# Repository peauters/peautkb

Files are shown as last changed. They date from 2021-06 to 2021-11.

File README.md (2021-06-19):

# Peautkb

## Intro
This is my first foray into custom built mechanical keyboards. I designed this as a mini project to get into pcb design and embedded code in `rust`. 

It has been awesome.

## Details
This board takes a lot of inspiration from the [Corne](https://github.com/foostan/crkbd) and [Kyria](https://blog.splitkb.com/blog/introducing-the-kyria) boards. 

I really liked the 3 rows from the Corne, as well as the rotaries from the Kyria. I wanted a single row thumb cluster and a column stager that fitted my hands. In then end, I ended up with what is in this repo.

## Firmware
Before I really had much info about open source keyboards, I decided I wanted to write my own firmware in `rust`. A well supported chip and board is the (WeAct MiniSTM32F4x1)[https://github.com/WeActTC/MiniSTM32F4x1] aka "the blackpill".

This board has a different footprint to a Pro Micro, which in hindsight has probably made this board very niche. I know of other blackpill boards (like the [Grandiceps](https://shop.tokas.co.uk/product/grandiceps-split-keyboard-kit/?v=79cba1185463)), but they seem limited at the moment.

The firmware is custom, written in `rust` using the [keyberon](https://github.com/TeXitoi/keyberon) as a base. At the moment, it manages communication between each side, the ssd1306 displays and has code to enable media keys in a second usb HID report. The most important feature is bongo cat animated displays. Thank you to [dancarrol](https://github.com/dancarroll/qmk-bongo) for the inspiration.

### How to build the firmware
- Install rust (see [here](https://www.rust-lang.org/tools/install))
- Install the compile target for the black-pills `rustup target install thumbv7em-none-eabihf`
- Install binutils to create a binary file `cargo install cargo-binutils` and `rustup component add llvm-tools-preview` 
- Build the binary `cargo objcopy --release -- -O binary out.bin`
- Put the black-pill in dfu boot loader. Hold the `NRST` and `BOOT0` buttons at the same time, then let go of `NRST` while still holding `BOOT0` button for a second longer.
- Check you can see it with `lsusb`
- Flash with dfu-util or similar
- Repeat for both sides

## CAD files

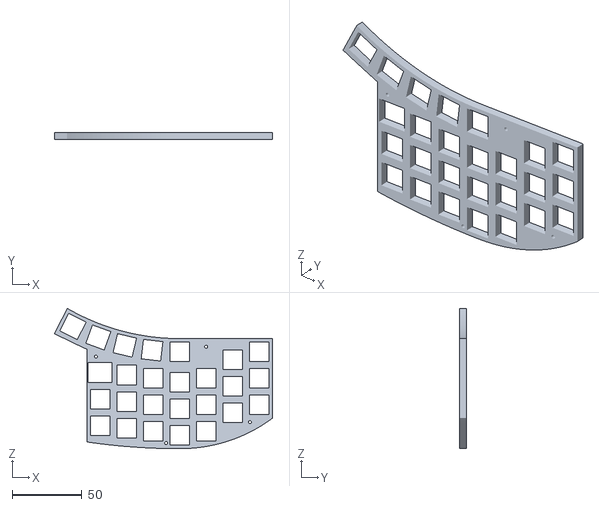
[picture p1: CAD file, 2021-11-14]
case/plate-right.stl
156.1 x 4.80 x 100.5

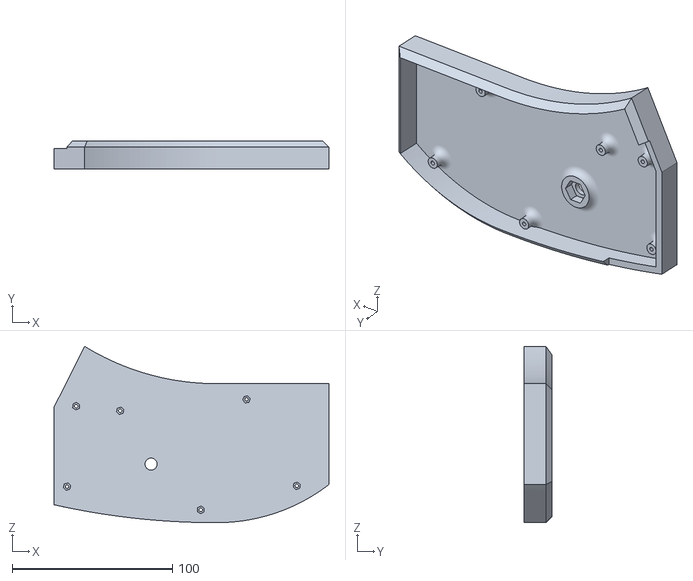
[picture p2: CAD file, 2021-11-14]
case/base-right.stl
171.8 x 17.5 x 110.1

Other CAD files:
case/base-left.stl
case/plate-left.stl

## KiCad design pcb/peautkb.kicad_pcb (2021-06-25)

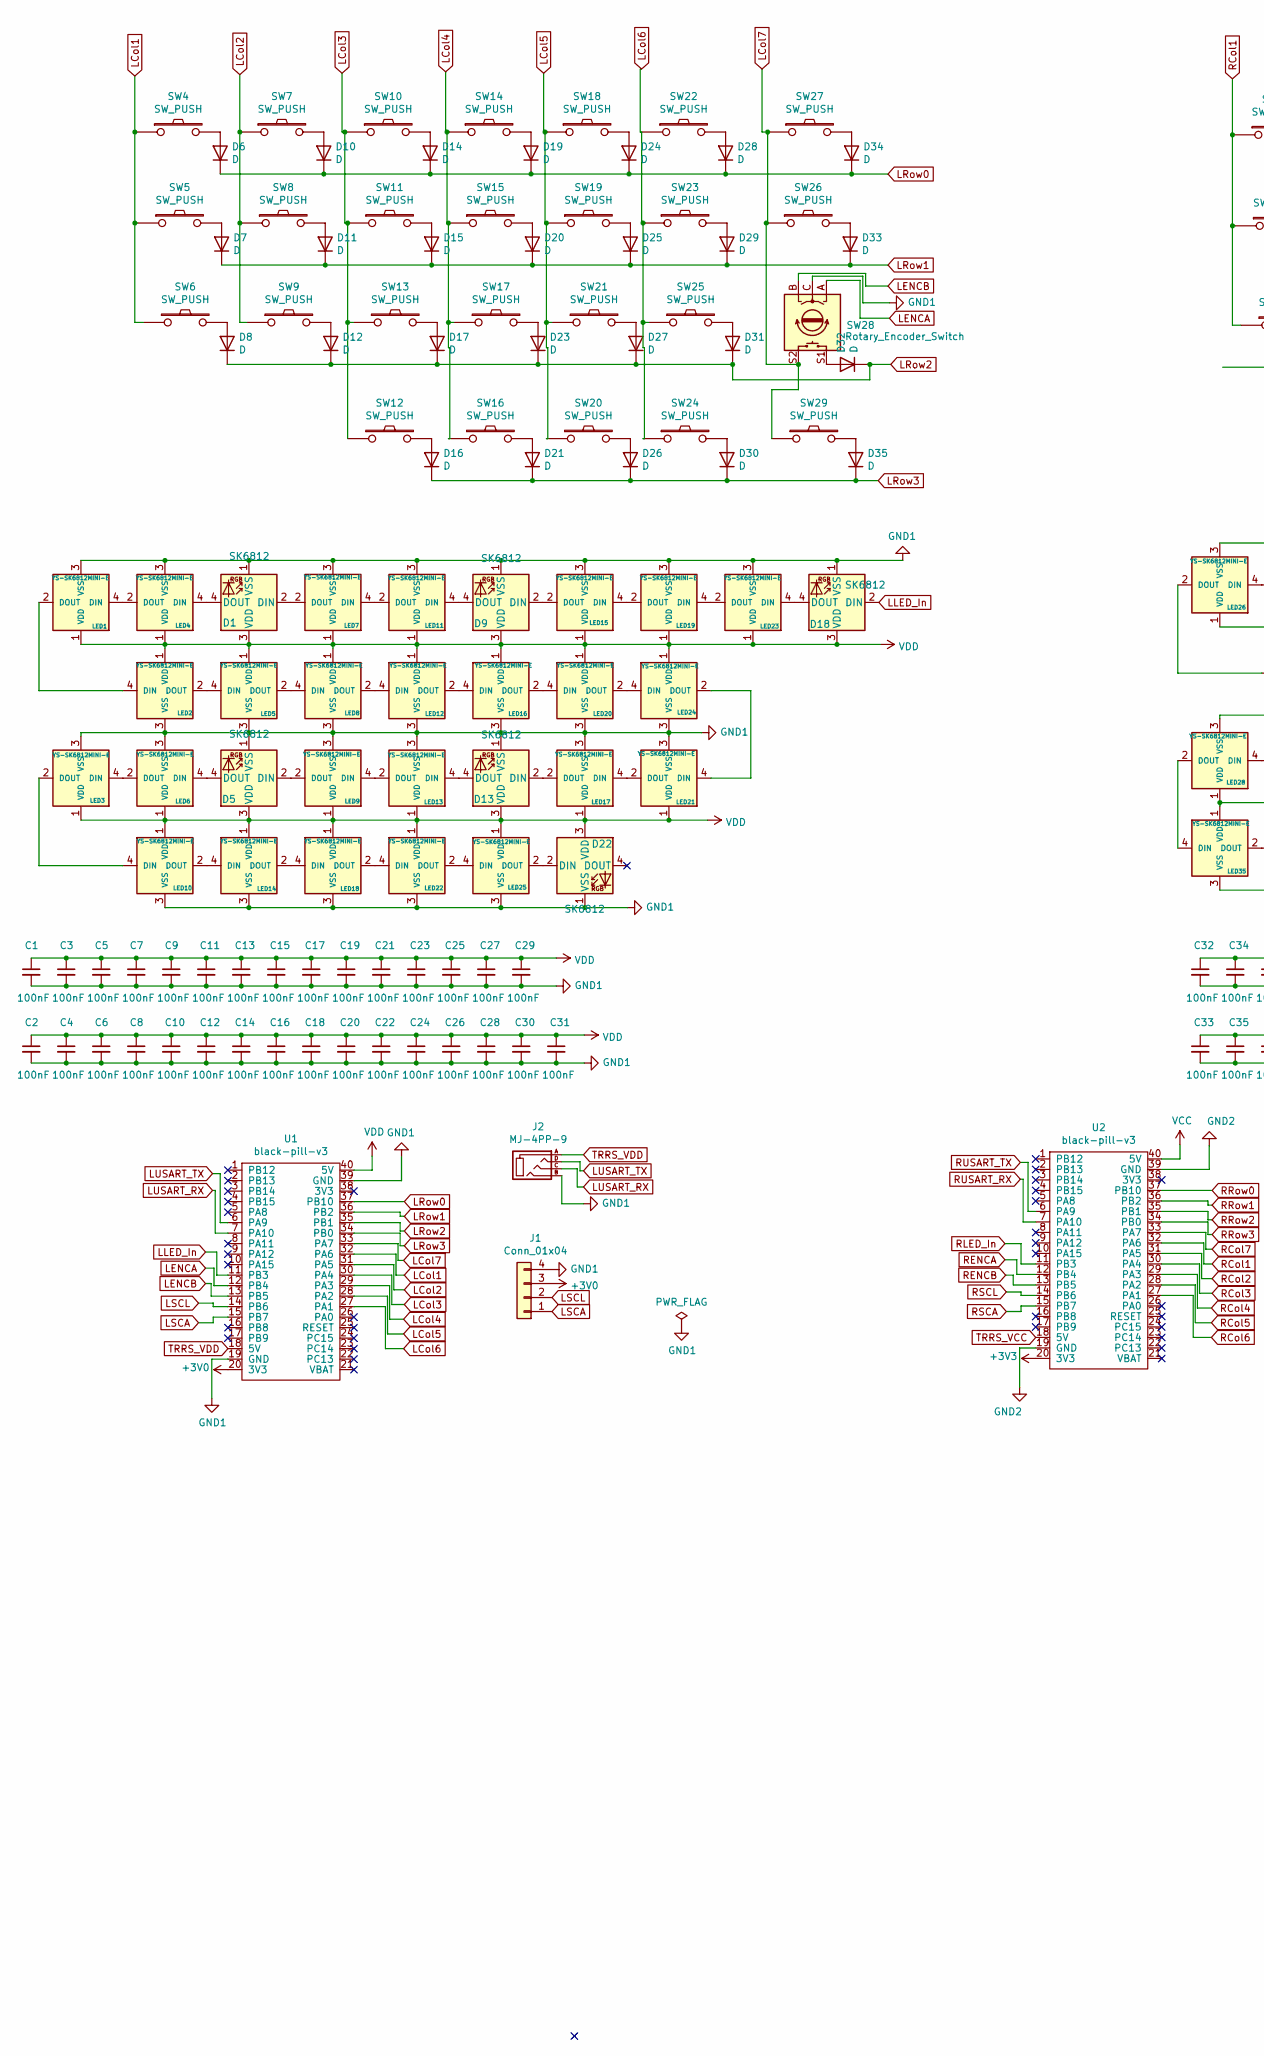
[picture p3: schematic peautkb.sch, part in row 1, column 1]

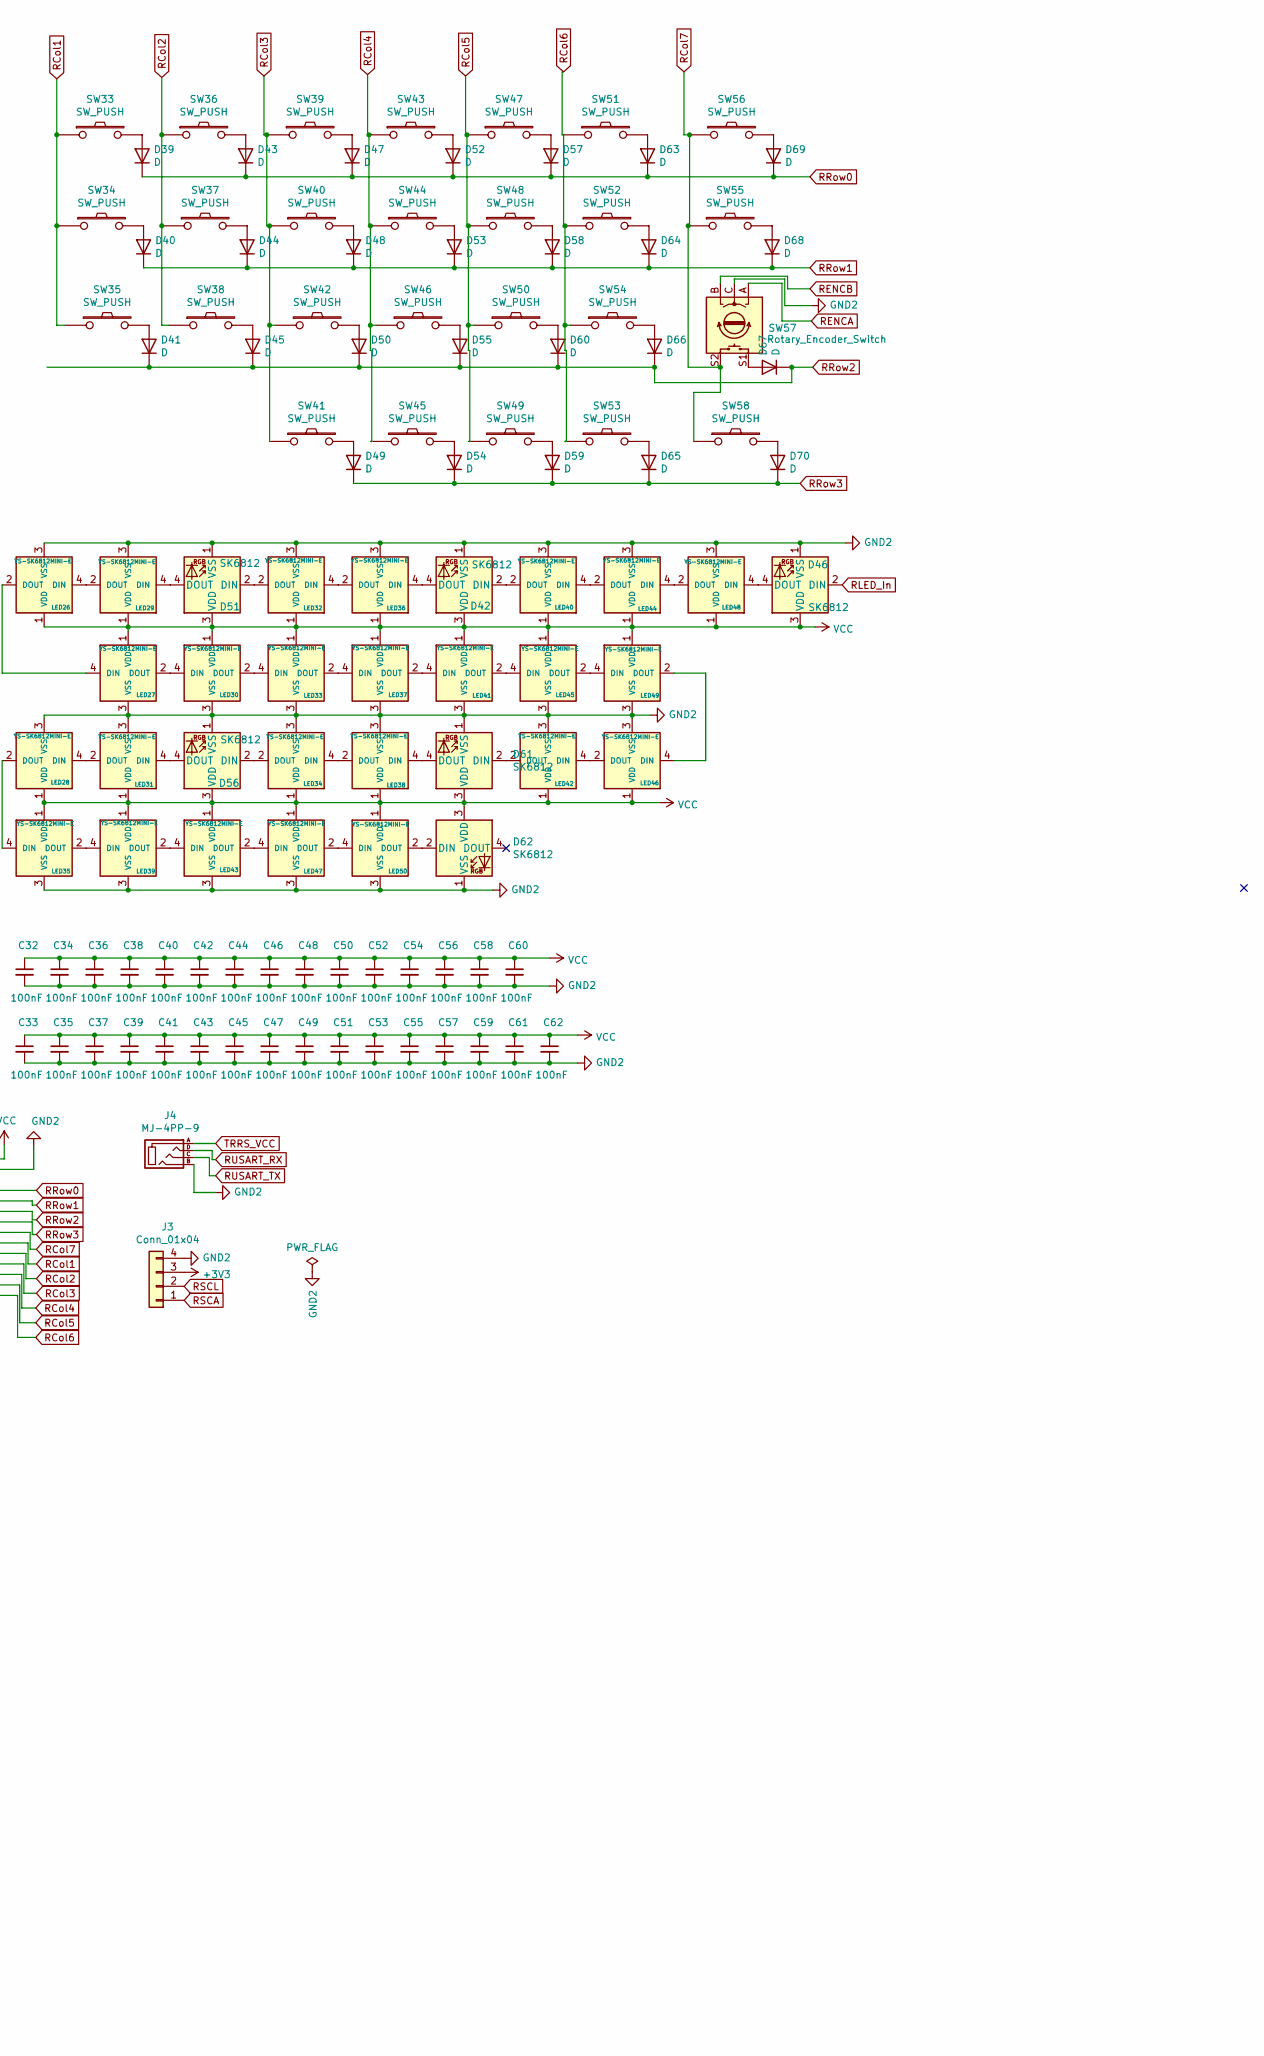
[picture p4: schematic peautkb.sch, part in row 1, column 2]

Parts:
C1, C2, C3, C4, C5, C6, C7, C8, C9, C10, C11, C12, C13, C14, C15, C16, C17, C18, C19, C20, C21, C22, C23, C24, C25, C26, C27, C28, C29, C30, C31, C32, C33, C34, C35, C36, C37, C38, C39, C40, C41, C42, C43, C44, C45, C46, C47, C48, C49, C50, C51, C52, C53, C54, C55, C56, C57, C58, C59, C60, C61, C62: 100nF; C_0805_2012Metric_Pad1.18x1.45mm_HandSolder
D1, D5, D9, D13, D18, D22, D42, D46, D51, D56, D61, D62: SK6812; LED_SK6812_PLCC4_5.0x5.0mm_P3.2mm
D6, D7, D8, D10, D11, D12, D14, D15, D16, D17, D19, D20, D21, D23, D24, D25, D26, D27, D28, D29, D30, D31, D32, D33, D34, D35, D39, D40, D41, D43, D44, D45, D47, D48, D49, D50, D52, D53, D54, D55, D57, D58, D59, D60, D63, D64, D65, D66, D67, D68, D69, D70: D; D3_SMD_v2
J1, J3: Conn_01x04; OLED_1side
J2, J4: MJ-4PP-9
LED1, LED2, LED3, LED4, LED5, LED6, LED7, LED8, LED9, LED10, LED11, LED12, LED13, LED14, LED15, LED16, LED17, LED18, LED19, LED20, LED21, LED22, LED23, LED24, LED25, LED26, LED27, LED28, LED29, LED30, LED31, LED32, LED33, LED34, LED35, LED36, LED37, LED38, LED39, LED40, LED41, LED42, LED43, LED44, LED45, LED46, LED47, LED48, LED49, LED50: YS-SK6812MINI-E
SW4, SW5, SW6, SW7, SW8, SW9, SW10, SW11, SW12, SW13, SW14, SW15, SW16, SW17, SW18, SW19, SW20, SW21, SW22, SW23, SW24, SW25, SW26, SW27, SW29, SW33, SW34, SW35, SW36, SW37, SW38, SW39, SW40, SW41, SW42, SW43, SW44, SW45, SW46, SW47, SW48, SW49, SW50, SW51, SW52, SW53, SW54, SW55, SW56, SW58: SW_PUSH; CherryMX_Hotswap
SW28, SW57: Rotary_Encoder_Switch; RotaryEncoder_Alps_EC11E-Switch_Vertical_H20mm
U1, U2: black-pill-v3

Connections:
+3V0: J1.3, U1.20 (3V3)
+3V3: J3.3, U2.20 (3V3)
GND1: C1.2, C2.2, C3.2, C4.2, C5.2, C6.2, C7.2, C8.2, C9.2, C10.2, C11.2, C12.2, C13.2, C14.2, C15.2, C16.2, C17.2, C18.2, C19.2, C20.2, C21.2, C22.2, C23.2, C24.2, C25.2, C26.2, C27.2, C28.2, C29.2, C30.2, C31.2, D1.1 (VSS), D5.1 (VSS), D9.1 (VSS), D13.1 (VSS), D18.1 (VSS), D22.1 (VSS), J1.4, J2.B, LED1.3 (VSS), LED2.3 (VSS), LED3.3 (VSS), LED4.3 (VSS), LED5.3 (VSS), LED6.3 (VSS), LED7.3 (VSS), LED8.3 (VSS), LED9.3 (VSS), LED10.3 (VSS), LED11.3 (VSS), LED12.3 (VSS), LED13.3 (VSS), LED14.3 (VSS), LED15.3 (VSS), LED16.3 (VSS), LED17.3 (VSS), LED18.3 (VSS), LED19.3 (VSS), LED20.3 (VSS), LED21.3 (VSS), LED22.3 (VSS), LED23.3 (VSS), LED24.3 (VSS), LED25.3 (VSS), SW28.C, U1.19 (GND), U1.39 (GND)
GND2: C32.2, C33.2, C34.2, C35.2, C36.2, C37.2, C38.2, C39.2, C40.2, C41.2, C42.2, C43.2, C44.2, C45.2, C46.2, C47.2, C48.2, C49.2, C50.2, C51.2, C52.2, C53.2, C54.2, C55.2, C56.2, C57.2, C58.2, C59.2, C60.2, C61.2, C62.2, D42.1 (VSS), D46.1 (VSS), D51.1 (VSS), D56.1 (VSS), D61.1 (VSS), D62.1 (VSS), J3.4, J4.B, LED26.3 (VSS), LED27.3 (VSS), LED28.3 (VSS), LED29.3 (VSS), LED30.3 (VSS), LED31.3 (VSS), LED32.3 (VSS), LED33.3 (VSS), LED34.3 (VSS), LED35.3 (VSS), LED36.3 (VSS), LED37.3 (VSS), LED38.3 (VSS), LED39.3 (VSS), LED40.3 (VSS), LED41.3 (VSS), LED42.3 (VSS), LED43.3 (VSS), LED44.3 (VSS), LED45.3 (VSS), LED46.3 (VSS), LED47.3 (VSS), LED48.3 (VSS), LED49.3 (VSS), LED50.3 (VSS), SW57.C, U2.19 (GND), U2.39 (GND)
LCol1: SW4.1, SW5.1, SW6.1, U1.32 (PA6)
LCol2: SW7.1, SW8.1, SW9.1, U1.31 (PA5)
LCol3: SW10.1, SW11.1, SW12.1, SW13.1, U1.30 (PA4)
LCol4: SW14.1, SW15.1, SW16.1, SW17.1, U1.29 (PA3)
LCol5: SW18.1, SW19.1, SW20.1, SW21.1, U1.28 (PA2)
LCol6: SW22.1, SW23.1, SW24.1, SW25.1, U1.27 (PA1)
LCol7: SW26.1, SW27.1, SW28.S2, SW29.1, U1.33 (PA7)
LENCA: SW28.A, U1.12 (PB4)
LENCB: SW28.B, U1.13 (PB5)
LLED_In: D18.2 (DIN), U1.11 (PB3)
LRow0: D6.1 (K), D10.1 (K), D14.1 (K), D19.1 (K), D24.1 (K), D28.1 (K), D34.1 (K), U1.37 (PB10)
LRow1: D7.1 (K), D11.1 (K), D15.1 (K), D20.1 (K), D25.1 (K), D29.1 (K), D33.1 (K), U1.36 (PB2)
LRow2: D8.1 (K), D12.1 (K), D17.1 (K), D23.1 (K), D27.1 (K), D31.1 (K), D32.1 (K), U1.35 (PB1)
LRow3: D16.1 (K), D21.1 (K), D26.1 (K), D30.1 (K), D35.1 (K), U1.34 (PB0)
LSCA: J1.1, U1.15 (PB7)
LSCL: J1.2, U1.14 (PB6)
LUSART_RX: J2.C, U1.7 (PA10)
LUSART_TX: J2.D, U1.6 (PA9)
unnamed: D1.2 (DIN), LED7.2 (DOUT)
unnamed: D1.4 (DOUT), LED4.4 (DIN)
unnamed: D5.2 (DIN), LED9.2 (DOUT)
unnamed: D5.4 (DOUT), LED6.4 (DIN)
unnamed: D6.2 (A), SW4.2
unnamed: D7.2 (A), SW5.2
unnamed: D8.2 (A), SW6.2
unnamed: D9.2 (DIN), LED15.2 (DOUT)
unnamed: D9.4 (DOUT), LED11.4 (DIN)
unnamed: D10.2 (A), SW7.2
unnamed: D11.2 (A), SW8.2
unnamed: D12.2 (A), SW9.2
unnamed: D13.2 (DIN), LED17.2 (DOUT)
unnamed: D13.4 (DOUT), LED13.4 (DIN)
unnamed: D14.2 (A), SW10.2
unnamed: D15.2 (A), SW11.2
unnamed: D16.2 (A), SW12.2
unnamed: D17.2 (A), SW13.2
unnamed: D18.4 (DOUT), LED23.4 (DIN)
unnamed: D19.2 (A), SW14.2
unnamed: D20.2 (A), SW15.2
unnamed: D21.2 (A), SW16.2
unnamed: D22.2 (DIN), LED25.2 (DOUT)
unnamed: D23.2 (A), SW17.2
unnamed: D24.2 (A), SW18.2
unnamed: D25.2 (A), SW19.2
unnamed: D26.2 (A), SW20.2
unnamed: D27.2 (A), SW21.2
unnamed: D28.2 (A), SW22.2
unnamed: D29.2 (A), SW23.2
unnamed: D30.2 (A), SW24.2
unnamed: D31.2 (A), SW25.2
unnamed: D32.2 (A), SW28.S1
unnamed: D33.2 (A), SW26.2
unnamed: D34.2 (A), SW27.2
unnamed: D35.2 (A), SW29.2
unnamed: D39.2 (A), SW33.2
unnamed: D40.2 (A), SW34.2
unnamed: D41.2 (A), SW35.2
unnamed: D42.2 (DIN), LED40.2 (DOUT)
unnamed: D42.4 (DOUT), LED36.4 (DIN)
unnamed: D43.2 (A), SW36.2
unnamed: D44.2 (A), SW37.2
unnamed: D45.2 (A), SW38.2
unnamed: D46.4 (DOUT), LED48.4 (DIN)
unnamed: D47.2 (A), SW39.2
unnamed: D48.2 (A), SW40.2
unnamed: D49.2 (A), SW41.2
unnamed: D50.2 (A), SW42.2
unnamed: D51.2 (DIN), LED32.2 (DOUT)
unnamed: D51.4 (DOUT), LED29.4 (DIN)
unnamed: D52.2 (A), SW43.2
unnamed: D53.2 (A), SW44.2
unnamed: D54.2 (A), SW45.2
unnamed: D55.2 (A), SW46.2
unnamed: D56.2 (DIN), LED34.2 (DOUT)
unnamed: D56.4 (DOUT), LED31.4 (DIN)
unnamed: D57.2 (A), SW47.2
unnamed: D58.2 (A), SW48.2
unnamed: D59.2 (A), SW49.2
unnamed: D60.2 (A), SW50.2
unnamed: D61.2 (DIN), LED42.2 (DOUT)
unnamed: D61.4 (DOUT), LED38.4 (DIN)
unnamed: D62.2 (DIN), LED50.2 (DOUT)
unnamed: D63.2 (A), SW51.2
unnamed: D64.2 (A), SW52.2
unnamed: D65.2 (A), SW53.2
unnamed: D66.2 (A), SW54.2
unnamed: D67.2 (A), SW57.S1
unnamed: D68.2 (A), SW55.2
unnamed: D69.2 (A), SW56.2
unnamed: D70.2 (A), SW58.2
unnamed: LED1.2 (DOUT), LED2.4 (DIN)
unnamed: LED1.4 (DIN), LED4.2 (DOUT)
unnamed: LED2.2 (DOUT), LED5.4 (DIN)
unnamed: LED3.4 (DIN), LED6.2 (DOUT)
unnamed: LED5.2 (DOUT), LED8.4 (DIN)
unnamed: LED10.2 (DOUT), LED14.4 (DIN)
unnamed: LED3.2 (DOUT), LED10.4 (DIN)
unnamed: LED7.4 (DIN), LED11.2 (DOUT)
unnamed: LED12.2 (DOUT), LED16.4 (DIN)
unnamed: LED8.2 (DOUT), LED12.4 (DIN)
unnamed: LED9.4 (DIN), LED13.2 (DOUT)
unnamed: LED14.2 (DOUT), LED18.4 (DIN)
unnamed: LED15.4 (DIN), LED19.2 (DOUT)
unnamed: LED16.2 (DOUT), LED20.4 (DIN)
unnamed: LED17.4 (DIN), LED21.2 (DOUT)
unnamed: LED18.2 (DOUT), LED22.4 (DIN)
unnamed: LED19.4 (DIN), LED23.2 (DOUT)
unnamed: LED20.2 (DOUT), LED24.4 (DIN)
unnamed: LED21.4 (DIN), LED24.2 (DOUT)
unnamed: LED22.2 (DOUT), LED25.4 (DIN)
unnamed: LED26.2 (DOUT), LED27.4 (DIN)
unnamed: LED26.4 (DIN), LED29.2 (DOUT)
unnamed: LED27.2 (DOUT), LED30.4 (DIN)
unnamed: LED28.2 (DOUT), LED35.4 (DIN)
unnamed: LED28.4 (DIN), LED31.2 (DOUT)
unnamed: LED30.2 (DOUT), LED33.4 (DIN)
unnamed: LED32.4 (DIN), LED36.2 (DOUT)
unnamed: LED33.2 (DOUT), LED37.4 (DIN)
unnamed: LED34.4 (DIN), LED38.2 (DOUT)
unnamed: LED35.2 (DOUT), LED39.4 (DIN)
unnamed: LED37.2 (DOUT), LED41.4 (DIN)
unnamed: LED39.2 (DOUT), LED43.4 (DIN)
unnamed: LED40.4 (DIN), LED44.2 (DOUT)
unnamed: LED41.2 (DOUT), LED45.4 (DIN)
unnamed: LED42.4 (DIN), LED46.2 (DOUT)
unnamed: LED43.2 (DOUT), LED47.4 (DIN)
unnamed: LED44.4 (DIN), LED48.2 (DOUT)
unnamed: LED45.2 (DOUT), LED49.4 (DIN)
unnamed: LED46.4 (DIN), LED49.2 (DOUT)
unnamed: LED47.2 (DOUT), LED50.4 (DIN)
RCol1: SW33.1, SW34.1, SW35.1, U2.32 (PA6)
RCol2: SW36.1, SW37.1, SW38.1, U2.31 (PA5)
RCol3: SW39.1, SW40.1, SW41.1, SW42.1, U2.30 (PA4)
RCol4: SW43.1, SW44.1, SW45.1, SW46.1, U2.29 (PA3)
RCol5: SW47.1, SW48.1, SW49.1, SW50.1, U2.28 (PA2)
RCol6: SW51.1, SW52.1, SW53.1, SW54.1, U2.27 (PA1)
RCol7: SW55.1, SW56.1, SW57.S2, SW58.1, U2.33 (PA7)
RENCA: SW57.A, U2.12 (PB4)
RENCB: SW57.B, U2.13 (PB5)
RLED_In: D46.2 (DIN), U2.11 (PB3)
RRow0: D39.1 (K), D43.1 (K), D47.1 (K), D52.1 (K), D57.1 (K), D63.1 (K), D69.1 (K), U2.37 (PB10)
RRow1: D40.1 (K), D44.1 (K), D48.1 (K), D53.1 (K), D58.1 (K), D64.1 (K), D68.1 (K), U2.36 (PB2)
RRow2: D41.1 (K), D45.1 (K), D50.1 (K), D55.1 (K), D60.1 (K), D66.1 (K), D67.1 (K), U2.35 (PB1)
RRow3: D49.1 (K), D54.1 (K), D59.1 (K), D65.1 (K), D70.1 (K), U2.34 (PB0)
RSCA: J3.1, U2.15 (PB7)
RSCL: J3.2, U2.14 (PB6)
RUSART_RX: J4.D, U2.7 (PA10)
RUSART_TX: J4.C, U2.6 (PA9)
TRRS_VCC: J4.A, U2.18 (5V)
TRRS_VDD: J2.A, U1.18 (5V)
VCC: C32.1, C33.1, C34.1, C35.1, C36.1, C37.1, C38.1, C39.1, C40.1, C41.1, C42.1, C43.1, C44.1, C45.1, C46.1, C47.1, C48.1, C49.1, C50.1, C51.1, C52.1, C53.1, C54.1, C55.1, C56.1, C57.1, C58.1, C59.1, C60.1, C61.1, C62.1, D42.3 (VDD), D46.3 (VDD), D51.3 (VDD), D56.3 (VDD), D61.3 (VDD), D62.3 (VDD), LED26.1 (VDD), LED27.1 (VDD), LED28.1 (VDD), LED29.1 (VDD), LED30.1 (VDD), LED31.1 (VDD), LED32.1 (VDD), LED33.1 (VDD), LED34.1 (VDD), LED35.1 (VDD), LED36.1 (VDD), LED37.1 (VDD), LED38.1 (VDD), LED39.1 (VDD), LED40.1 (VDD), LED41.1 (VDD), LED42.1 (VDD), LED43.1 (VDD), LED44.1 (VDD), LED45.1 (VDD), LED46.1 (VDD), LED47.1 (VDD), LED48.1 (VDD), LED49.1 (VDD), LED50.1 (VDD), U2.40 (5V)
VDD: C1.1, C2.1, C3.1, C4.1, C5.1, C6.1, C7.1, C8.1, C9.1, C10.1, C11.1, C12.1, C13.1, C14.1, C15.1, C16.1, C17.1, C18.1, C19.1, C20.1, C21.1, C22.1, C23.1, C24.1, C25.1, C26.1, C27.1, C28.1, C29.1, C30.1, C31.1, D1.3 (VDD), D5.3 (VDD), D9.3 (VDD), D13.3 (VDD), D18.3 (VDD), D22.3 (VDD), LED1.1 (VDD), LED2.1 (VDD), LED3.1 (VDD), LED4.1 (VDD), LED5.1 (VDD), LED6.1 (VDD), LED7.1 (VDD), LED8.1 (VDD), LED9.1 (VDD), LED10.1 (VDD), LED11.1 (VDD), LED12.1 (VDD), LED13.1 (VDD), LED14.1 (VDD), LED15.1 (VDD), LED16.1 (VDD), LED17.1 (VDD), LED18.1 (VDD), LED19.1 (VDD), LED20.1 (VDD), LED21.1 (VDD), LED22.1 (VDD), LED23.1 (VDD), LED24.1 (VDD), LED25.1 (VDD), U1.40 (5V)

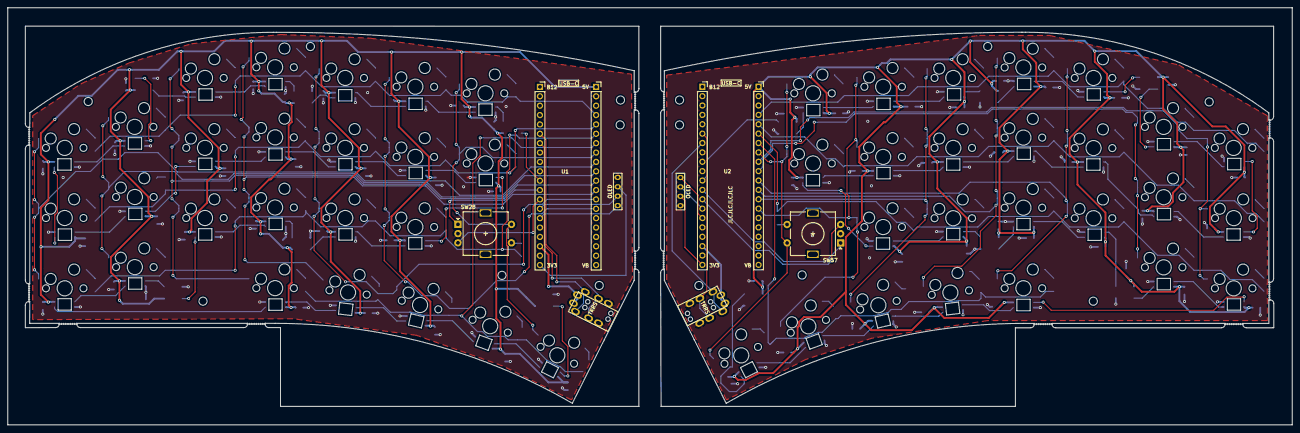
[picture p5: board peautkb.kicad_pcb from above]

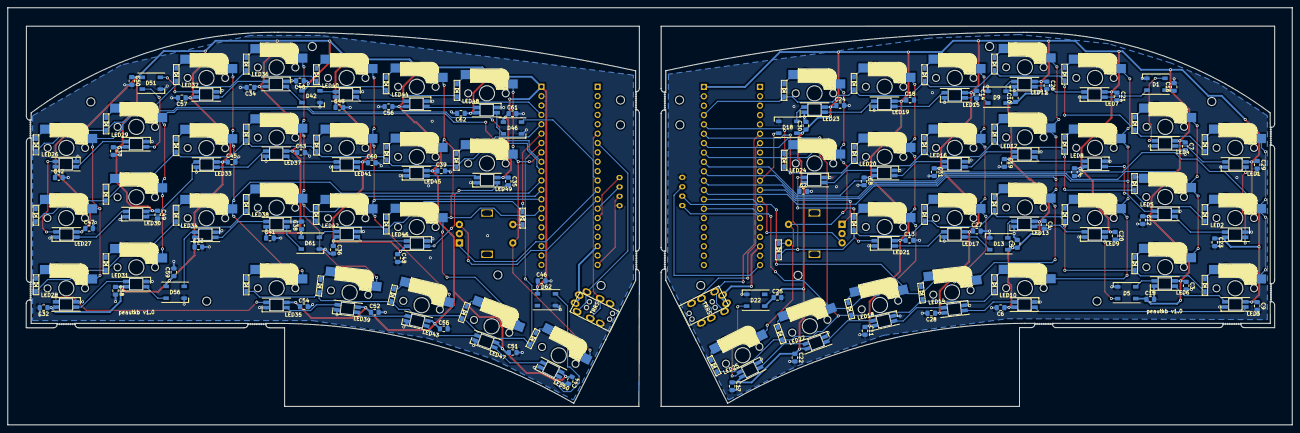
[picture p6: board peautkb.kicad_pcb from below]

Board: 2 copper layers, 348.0 x 113.0 mm, 248 parts (176 on the bottom side), 156 nets.

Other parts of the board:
Ref**: Val**; M2_HOLE_v2
Ref**#2, Ref**#3, Ref**#4, Ref**#5, Ref**#6, Ref**#7, Ref**#8, Ref**#9, Ref**#10, Ref**#11, Ref**#12, Ref**#13, Ref**#14: Val**; M2_HOLE_v2

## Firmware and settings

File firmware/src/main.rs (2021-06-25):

#![no_main]
#![no_std]

use defmt_rtt as _; // global logger
use panic_probe as _;

use rtic::app;

use stm32f4xx_hal as hal;

pub mod custom_action;
pub mod dispatcher;
pub mod keyboard;
pub mod keymap;
pub(crate) mod multi;
pub mod rotary;
pub mod serial;

#[app(device = crate::hal::stm32, peripherals = true, dispatchers = [SPI4, SPI5, SPI6])]
mod app {

    use crate::custom_action::*;
    use crate::dispatcher::display::OLED;
    use crate::dispatcher::*;
    use crate::keyboard::*;
    use crate::keymap::LAYERS;
    use crate::rotary::*;
    use crate::serial::*;

    use core::convert::Infallible;

    use crate::hal::{
        gpio::{gpioa, gpiob, Edge, Input, Output, PullUp, PushPull},
        otg_fs,
        prelude::*,
        stm32, timer,
    };
    use dwt_systick_monotonic::DwtSystick;
    use rtic::time::duration::Milliseconds;

    use embedded_hal::digital::v2::{InputPin, OutputPin};
    use generic_array::typenum::{U4, U7};
    use keyberon::debounce::Debouncer;
    use keyberon::hid;
    use keyberon::impl_heterogenous_array;
    use keyberon::layout::{Event, Layout};
    use keyberon::matrix::{Matrix, PressedKeys};
    use stm32f4xx_hal::dma::StreamsTuple;

    use crate::app;

    use usb_device::bus::UsbBusAllocator;
    use usb_device::class::UsbClass as _;
    use usb_device::device::UsbDeviceState;
    use usb_device::prelude::*;

    #[monotonic(binds = SysTick, default = true)]
    type Mono = DwtSystick<48_000_000>; // 48 MHz

    type UsbMediaKeysClass = hid::HidClass<'static, otg_fs::UsbBusType, Peautkb>;
    type UsbDevice = usb_device::device::UsbDevice<'static, otg_fs::UsbBusType>;
    /// USB VIP for a generic keyboard from
    /// https://github.com/obdev/v-usb/blob/master/usbdrv/USB-IDs-for-free.txt
    const VID: u16 = 0x16c0;

    /// USB PID for a generic keyboard from
    /// https://github.com/obdev/v-usb/blob/master/usbdrv/USB-IDs-for-free.txt
    const PID: u16 = 0x27db;

    pub struct Cols(
        gpioa::PA6<Input<PullUp>>,
        gpioa::PA5<Input<PullUp>>,
        gpioa::PA4<Input<PullUp>>,
        gpioa::PA3<Input<PullUp>>,
        gpioa::PA2<Input<PullUp>>,
        gpioa::PA1<Input<PullUp>>,
        gpioa::PA7<Input<PullUp>>,
    );
    impl_heterogenous_array! {
        Cols,
        dyn InputPin<Error = Infallible>,
        U7,
        [0, 1, 2, 3, 4, 5, 6]
    }
    pub struct Rows(
        gpiob::PB10<Output<PushPull>>,
        gpiob::PB2<Output<PushPull>>,
        gpiob::PB1<Output<PushPull>>,
        gpiob::PB0<Output<PushPull>>,
    );
    impl_heterogenous_array! {
        Rows,
        dyn OutputPin<Error = Infallible>,
        U4,
        [0, 1, 2, 3]
    }

    #[resources]
    struct Resources {
        scan_timer: timer::Timer<stm32::TIM3>,
        tick_timer: timer::Timer<stm32::TIM4>,
        usb_dev: app::UsbDevice,
        usb_mediakeys_class: app::UsbMediaKeysClass,
        tx: TxComms,
        rx: RxComms,
        dispatcher: Dispatcher,
        matrix: Matrix<app::Cols, app::Rows>,
        debouncer: Debouncer<PressedKeys<U4, U7>>,
        layout: Layout<PkbAction>,
        initd: bool,
        timer_init: bool,
        rotary: Rotary,
        custom_action_state: CustomActionState,
    }

    static mut EP_MEMORY: [u32; 1024] = [0; 1024];

    #[init]
    fn init(mut c: init::Context) -> (init::LateResources, init::Monotonics) {
        static mut USB_BUS: Option<UsbBusAllocator<otg_fs::UsbBusType>> = None;
        let mut perfs: stm32::Peripherals = c.device;

        let rcc = perfs.RCC.constrain();
        let mut syscfg = perfs.SYSCFG.constrain();
        let clocks = rcc
            .cfgr
            .sysclk(48.mhz())
            .pclk1(24.mhz())
            .use_hse(25.mhz())
            .freeze();

        let mono = DwtSystick::new(&mut c.core.DCB, c.core.DWT, c.core.SYST, clocks.hclk().0);

        let gpioa = perfs.GPIOA.split();
        let gpiob = perfs.GPIOB.split();

        let scan_timer = timer::Timer::tim3(perfs.TIM3, 1000.hz(), clocks);
        let tick_timer = timer::Timer::tim4(perfs.TIM4, 24.hz(), clocks);

        // I2C for SSD1306 display
        let pb6 = gpiob
            .pb6
            .into_alternate_af4()
            .internal_pull_up(true)
            .set_open_drain();
        let pb7 = gpiob
            .pb7
            .into_alternate_af4()
            .internal_pull_up(true)
            .set_open_drain();
        let display = OLED::new(perfs.I2C1, pb6, pb7, clocks);

        // Rotary encoder pins
        let pb4 = gpiob.pb4.into_pull_up_input();
        let mut pb5 = gpiob.pb5.into_pull_up_input();

        pb5.make_interrupt_source(&mut syscfg);
        pb5.enable_interrupt(&mut perfs.EXTI);
        pb5.trigger_on_edge(&mut perfs.EXTI, Edge::RISING_FALLING);

        let rotary = Rotary::new(pb4, pb5, (3, 0), (3, 1));

        // USB keyboard
        let usb = otg_fs::USB {
            usb_global: perfs.OTG_FS_GLOBAL,
            usb_device: perfs.OTG_FS_DEVICE,
            usb_pwrclk: perfs.OTG_FS_PWRCLK,
            pin_dm: gpioa.pa11.into_alternate_af10(),
            pin_dp: gpioa.pa12.into_alternate_af10(),
            hclk: clocks.hclk(),
        };
        *USB_BUS = Some(otg_fs::UsbBusType::new(usb, unsafe { &mut EP_MEMORY }));
        let usb_bus = USB_BUS.as_ref().unwrap();

        let usb_mediakeys_class = hid::HidClass::new(Peautkb::default(), usb_bus);
        let usb_dev = UsbDeviceBuilder::new(usb_bus, UsbVidPid(VID, PID))
            .manufacturer("peauters.dev")
            .product("peautkb")
            .serial_number(env!("CARGO_PKG_VERSION"))
            .build();

        // Inter-board comms
        let pa9 = gpioa.pa9.into_alternate_af7();
        let pa10 = gpioa.pa10.into_alternate_af7();

        let (tx, rx) = create_comms(perfs.USART1, pa9, pa10, clocks);

        // Keyberon setup
        let matrix = Matrix::new(
            Cols(
                gpioa.pa6.into_pull_up_input(),
                gpioa.pa5.into_pull_up_input(),
                gpioa.pa4.into_pull_up_input(),
                gpioa.pa3.into_pull_up_input(),
                gpioa.pa2.into_pull_up_input(),
                gpioa.pa1.into_pull_up_input(),
                gpioa.pa7.into_pull_up_input(),
            ),
            Rows(
                gpiob.pb10.into_push_pull_output(),
                gpiob.pb2.into_push_pull_output(),
                gpiob.pb1.into_push_pull_output(),
                gpiob.pb0.into_push_pull_output(),
            ),
        )
        .unwrap();

        let debouncer = Debouncer::new(PressedKeys::default(), PressedKeys::default(), 5);

        let layout = Layout::new(LAYERS);

        let steams = StreamsTuple::new(perfs.DMA1);
        let stream = steams.4;

        let leds = leds::LEDs::new(perfs.SPI2, gpiob.pb15.into_alternate_af5(), clocks, stream);

        ping::spawn_after(Milliseconds::new(4000_u32)).ok();

        (
            init::LateResources {
                scan_timer,
                tick_timer,
                usb_mediakeys_class,
                usb_dev,
                tx,
                rx,
                dispatcher: Dispatcher::new(display, leds),
                initd: false,
                matrix,
                debouncer,
                layout,
                timer_init: false,
                rotary,
                custom_action_state: CustomActionState::new(),
            },
            init::Monotonics(mono),
        )
    }

    #[idle]
    fn idle(_: idle::Context) -> ! {
        loop {
            core::hint::spin_loop()
        }
    }

    #[task(binds = USART1, priority = 3, resources = [rx, initd, layout, custom_action_state])]
    fn rx(c: rx::Context) {
        let rx::Resources {
            mut rx,
            mut initd,
            mut layout,
            mut custom_action_state,
        } = c.resources;

        initd.lock(|b| {
            if !*b {
                late_init::spawn_after(Milliseconds::new(4000_u32)).ok();
                *b = true;
            } else {
                rx.lock(|rx| {
                    if let Some(message) = rx.read_event() {
                        dispatch_event::spawn(message).ok();
                        match message {
                            Message::SecondaryKeyPress(i, j) => {
                                layout.lock(|l| {
                                    l.event(Event::Press(i, j));
                                    custom_action_state.lock(|c| {
                                        let messages = c.process(l.tick());
                                        for m in messages.into_iter() {
                                            dispatch_event::spawn(m).ok();
                                        }
                                    });
                                });
                                send_hid_report::spawn().ok();
                            }
                            Message::SecondaryKeyRelease(i, j) => {
                                layout.lock(|l| {
                                    l.event(Event::Release(i, j));
                                    custom_action_state.lock(|c| {
                                        let messages = c.process(l.tick());
                                        for m in messages.into_iter() {
                                            dispatch_event::spawn(m).ok();
                                        }
                                    });
                                });
                                send_hid_report::spawn().ok();
                            }
                            _ => (),
                        }
                    }
                });
            }
        });
    }

    #[task(binds = OTG_FS, priority = 4, resources = [usb_dev, usb_mediakeys_class, initd])]
    fn usb_rx(c: usb_rx::Context) {
        let usb_rx::Resources {
            mut usb_dev,
            mut usb_mediakeys_class,
            mut initd,
        } = c.resources;
        usb_dev.lock(|dev| {
            usb_mediakeys_class.lock(|mk| {
                if dev.poll(&mut [mk]) {
                    mk.poll();
                }
            })
        });
        initd.lock(|b| {
            if !*b {
                late_init::spawn_after(Milliseconds::new(1000_u32)).ok();
                *b = true;
            }
        });
    }

    #[task(binds = OTG_FS_WKUP, priority = 2, resources = [usb_dev, usb_mediakeys_class])]
    fn usb_wkup(c: usb_wkup::Context) {
        let usb_wkup::Resources {
            mut usb_dev,
            mut usb_mediakeys_class,
        } = c.resources;
        usb_dev.lock(|dev| {
            usb_mediakeys_class.lock(|mk| {
                if dev.poll(&mut [mk]) {
                    mk.poll();
                }
            })
        });
    }

    #[task(binds = EXTI9_5, priority = 2, resources = [rotary, layout, custom_action_state])]
    fn rot5(c: rot5::Context) {
        let rot5::Resources {
            mut rotary,
            mut layout,
            mut custom_action_state,
        } = c.resources;
        let mut dirty = false;
        layout.lock(|l| {
            rotary.lock(|r| {
                r.clear_interrupt();
                for event in r.poll() {
                    dirty = true;
                    l.event(event);
                    match event {
                        Event::Press(i, j) => {
                            dispatch_event::spawn(Message::MatrixKeyPress(i, j)).ok();
                        }
                        Event::Release(i, j) => {
                            dispatch_event::spawn(Message::MatrixKeyRelease(i, j)).ok();
                        }
                    }
                    custom_action_state.lock(|c| {
                        let messages = c.process(l.tick());
                        for m in messages.into_iter() {
                            dispatch_event::spawn(m).ok();
                        }
                    });
                }
            });
        });

        if dirty {
            send_hid_report::spawn().ok();
        }
    }

    #[task(binds = TIM3,
            priority = 3,
            resources = [scan_timer, debouncer, matrix, layout, custom_action_state, rotary])]
    fn scan(c: scan::Context) {
        let scan::Resources {
            mut scan_timer,
            mut debouncer,
            mut matrix,
            mut layout,
            mut custom_action_state,
            mut rotary,
        } = c.resources;
        scan_timer.lock(|t| t.wait().ok());

        let mut dirty = false;

        let pressed_keys = matrix.lock(|m| m.get().unwrap());
        layout.lock(|l| {
            debouncer.lock(|d| {
                rotary.lock(|r| {
                    for event in d.events(pressed_keys).chain(r.release()) {
                        dirty = true;
                        l.event(event);
                        match event {
                            Event::Press(i, j) => {
                                dispatch_event::spawn(Message::MatrixKeyPress(i, j)).ok();
                            }
                            Event::Release(i, j) => {
                                dispatch_event::spawn(Message::MatrixKeyRelease(i, j)).ok();
                            }
                        }
                    }
                    custom_action_state.lock(|c| {
                        let messages = c.process(l.tick());

                        for m in messages.into_iter() {
                            dispatch_event::spawn(m).ok();
                        }
                    });
                    custom_action_state.lock(|c| {
                        for m in c.check_layout_for_events(l) {
                            dispatch_event::spawn(m).ok();
                        }
                    });
                })
            });
        });

        send_hid_report::spawn().ok();
    }

    #[task(binds = TIM4,
        priority = 3,
        resources = [tick_timer])]
    fn tick(c: tick::Context) {
        let tick::Resources { mut tick_timer } = c.resources;
        tick_timer.lock(|t| t.wait().ok());

        dispatch_event::spawn(Message::UpdateDisplay).ok();
    }

    #[task(resources = [layout, usb_dev, usb_mediakeys_class, custom_action_state], priority = 2, capacity = 64)]
    fn send_hid_report(c: send_hid_report::Context) {
        let send_hid_report::Resources {
            mut layout,
            mut usb_dev,
            mut usb_mediakeys_class,
            mut custom_action_state,
        } = c.resources;

        while let Some(mut mk_report) = custom_action_state.lock(|c| c.get_mk_report()) {
            if usb_mediakeys_class.lock(|k| k.device_mut().set_report(mk_report.clone()))
                && usb_dev.lock(|d| d.state()) == UsbDeviceState::Configured
            {
                while let Ok(0) = usb_mediakeys_class.lock(|m| m.write(mk_report.as_bytes())) {}
            }
        }
        let mut report: KbHidReport = layout.lock(|l| l.keycodes().collect());
        custom_action_state.lock(|c| c.modify_kb_report(&mut report));
        if usb_mediakeys_class.lock(|k| k.device_mut().set_kb_report(report.clone()))
            && usb_dev.lock(|d| d.state()) == UsbDeviceState::Configured
        {
            while let Ok(0) = usb_mediakeys_class.lock(|k| k.write(report.as_bytes())) {}
        }
    }

    #[task(resources = [dispatcher, tx, timer_init, scan_timer, tick_timer, layout], priority = 1, capacity = 30)]
    fn dispatch_event(c: dispatch_event::Context, message: Message) {
        let dispatch_event::Resources {
            mut dispatcher,
            mut tx,
            mut timer_init,
            mut scan_timer,
            mut tick_timer,
            mut layout,
        } = c.resources;

        dispatcher.lock(|d| {
            if message == Message::UpdateDisplay {
                d.update_display();
            }
            d.dispatch(message)
                .map(Message::to_type)
                .for_each(|t| match t {
                    MessageType::Local(m) => {
                        dispatch_event::spawn(m).ok();
                        match m {
                            Message::InitTimers => timer_init.lock(|t| {
                                if !*t {
                                    scan_timer.lock(|t| t.listen(timer::Event::TimeOut));
                                    tick_timer.lock(|t| t.listen(timer::Event::TimeOut));
                                    *t = true;
                                }
                            }),
                            Message::SetDefaultLayer(i) => {
                                layout.lock(|l| l.set_default_layer(i));
                            }
                            _ => (),
                        }
                    }
                    MessageType::Remote(m) => tx.lock(|t| t.send_event(m)),
                })
        });
    }

    #[task(resources = [tx, initd])]
    fn ping(c: ping::Context) {
        defmt::info!("Pinging ... ");
        let ping::Resources { mut tx, mut initd } = c.resources;
        initd.lock(|i| {
            if !*i {
                tx.lock(|t| t.send_event(Message::Ping))
            }
        });
    }

    #[task(resources = [usb_dev, custom_action_state])]
    fn late_init(c: late_init::Context) {
        let late_init::Resources {
            mut usb_dev,
            mut custom_action_state,
        } = c.resources;
        defmt::info!("late init");
        dispatch_event::spawn(Message::LateInit).ok();

        if usb_dev.lock(|d| d.state()) == UsbDeviceState::Configured {
            dispatch_event::spawn(Message::YouArePrimary).ok();
            dispatch_event::spawn(Message::UsbConnected(true)).ok();
            custom_action_state.lock(|l| l.is_primary());
        } else {
            dispatch_event::spawn(Message::YouAreSecondary).ok();
        }
    }
}

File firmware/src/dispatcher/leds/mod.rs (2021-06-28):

use super::*;

use crate::hal::{
    gpio::{gpiob::PB15, Alternate, AF5},
    prelude::*,
    rcc::Clocks,
    spi::{NoMiso, NoSck, Spi},
    stm32,
};

use embedded_graphics::{
    fonts::{Font6x8, Text},
    pixelcolor::BinaryColor,
    style::TextStyleBuilder,
};

use numtoa::NumToA;
use smart_leds::RGB8;

mod driver;
mod fade;
mod off;
mod solid;
mod wheel;

use driver::Ws2812;
use stm32f4xx_hal::{
    dma::{Channel0, Stream4},
    spi::Tx,
};

#[derive(Copy, Clone, Serialize, Deserialize, PartialEq, Eq)]
pub enum Mode {
    Off,
    Wheel,
    Solid,
    Fade,
}

impl From<Mode> for &str {
    fn from(mode: Mode) -> Self {
        match mode {
            Mode::Off => "off",
            Mode::Wheel => "wheel",
            Mode::Solid => "solid",
            Mode::Fade => "fade",
        }
    }
}

#[derive(Copy, Clone, Serialize, Deserialize, PartialEq, Eq)]
pub enum Action {
    SetMode(Mode),
    IncrementRed,
    DecrementRed,
    IncrementGreen,
    DecrementGreen,
    IncrementBlue,
    DecrementBlue,
    Solid(solid::Solid),
    Update,
}
#[derive(Copy, Clone, Default)]
struct LEDMatrix {
    keys: [[RGB8; 7]; 3],
    thumb: [RGB8; 5],
    underglow: [RGB8; 6],
}

impl LEDMatrix {
    fn iter(self) -> Iter {
        Iter { matrix: self, i: 0 }
    }
}

impl IntoIterator for LEDMatrix {
    type Item = RGB8;

    type IntoIter = Iter;

    fn into_iter(self) -> Self::IntoIter {
        self.iter()
    }
}

struct Iter {
    matrix: LEDMatrix,
    i: usize,
}
impl Iterator for Iter {
    type Item = RGB8;

    fn next(&mut self) -> Option<Self::Item> {
        if self.i < 32 {
            let i = self.i;
            self.i += 1;
            match i {
                0 => Some(self.matrix.underglow[2]),
                1..=3 => Some(self.matrix.keys[0][7 - i]),
                4 => Some(self.matrix.underglow[1]),
                5..=6 => Some(self.matrix.keys[0][8 - i]),
                7 => Some(self.matrix.underglow[0]),
                8..=9 => Some(self.matrix.keys[0][9 - i]),
                10..=16 => Some(self.matrix.keys[1][i - 10]),
                17..=18 => Some(self.matrix.keys[2][22 - i]),
                19 => Some(self.matrix.underglow[4]),
                20..=21 => Some(self.matrix.keys[2][23 - i]),
                22 => Some(self.matrix.underglow[3]),
                23..=24 => Some(self.matrix.keys[2][24 - i]),
                25..=29 => Some(self.matrix.thumb[i - 25]),
                30 => Some(self.matrix.underglow[5]),
                _ => None,
            }
        } else {
            None
        }
    }
}

trait LEDMode {
    fn next_matrix(&mut self, last: LEDMatrix) -> Option<LEDMatrix>;
}

pub struct LEDs {
    leds: Ws2812<Stream4<stm32::DMA1>, Channel0, Tx<stm32::SPI2>, &'static mut [u8; 512]>,
    last: LEDMatrix,
    mode: Mode,
    solid_rgb: solid::Solid,
    off: off::Off,
    wheel: wheel::Wheel,
    fade: fade::FadeAfterRelease,
    sleep: bool,
}

impl LEDs {
    pub fn new(
        spi2: stm32::SPI2,
        pb15: PB15<Alternate<AF5>>,
        clocks: Clocks,
        stream: Stream4<stm32::DMA1>,
    ) -> Self {
        let spi = Spi::spi2(
            spi2,
            (NoSck, NoMiso, pb15),
            ws2812_spi::MODE,
            3_000_000.hz(),
            clocks,
        );

        let buffer = cortex_m::singleton!(: [u8; 512] = [0; 512]).unwrap();
        let next_buffer = cortex_m::singleton!(: [u8; 512] = [0; 512]).unwrap();

        let leds = Ws2812::new(stream, spi.use_dma().tx(), buffer, next_buffer);

        LEDs {
            leds,
            last: LEDMatrix::default(),
            mode: Mode::Solid,
            solid_rgb: solid::Solid::new(),
            off: off::Off::new(),
            wheel: wheel::Wheel::new(),
            fade: fade::FadeAfterRelease::new(),
            sleep: false,
        }
    }

    fn choose_mode(&mut self, mode: Mode) {
        self.mode = mode;
        self.update_leds();
    }

    fn update_leds(&mut self) {
        match (self.sleep, self.mode) {
            (true, _) => (),
            (_, Mode::Off) => self.off(),
            (_, Mode::Solid) => self.solid(),
            (_, Mode::Wheel) => self.wheel(),
            (_, Mode::Fade) => self.fade(),
        }
    }

    fn tick(&mut self) {
        match self.mode {
            _ => self.update_leds(),
        }
    }

    fn off(&mut self) {
        let matrix = self.off.next_matrix(self.last);
        self.write_all(matrix);
    }

    fn solid(&mut self) {
        let matrix = self.solid_rgb.next_matrix(self.last);
        self.write_all(matrix);
    }

    fn wheel(&mut self) {
        let matrix = self.wheel.next_matrix(self.last);
        self.write_all(matrix);
    }

    fn fade(&mut self) {
        let matrix = self.fade.next_matrix(self.last);
        self.write_all(matrix);
    }

    fn write_all(&mut self, matrix: Option<LEDMatrix>) {
        if let Some(next) = matrix {
            self.leds.write(next);
            self.last = next;
        }
    }
}
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

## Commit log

2021-03-27 before pcb layout
    [peautkb.kicad_pcb, peautkb.sch, plate v4.dxf]
2021-03-27 removes extra col
    [peautkb.sch, plate v4.dxf]
2021-03-28 left side traces completed
    [peautkb.kicad_pcb, peautkb.sch]
2021-03-29 aadded decoup caps to LHS
    [peautkb.kicad_pcb, peautkb.sch]
2021-03-29 finished RHS
    [peautkb.kicad_pcb]
2021-03-30 generate gerbers
    [peautkb-B_Cu.gbr, peautkb-B_Mask.gbr, peautkb-B_Paste.gbr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]
2021-03-31 added practice pads
    [peautkb.kicad_pcb]
2021-04-01 logo and final OLED placement
    [peautkb-B_Cu.gbr, peautkb-B_Mask.gbr, peautkb-B_Paste.gbr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]
2021-04-02 pcb tweaks
    [peautkb.kicad_pcb]
2021-04-02 initial firmware with rtic timer working
2021-04-10 updated rotary encoder pins to avoid crystal
    [peautkb.kicad_pcb, peautkb.sch]
2021-04-11 LED working, usb hid working, display working (on reset), example interrupt on a1
    [main.rs]
2021-04-14 before 4->2 layer rework
    [peautkb-B_Cu.gbr, peautkb-B_Mask.gbr, peautkb-B_Paste.gbr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]
2021-04-14 re-worked with copper pours for gnd and 5v routed, re-routed the LHS completely
    [peautkb.kicad_pcb]
2021-04-19 submitted pcbs - i hope
    [peautkb-B_Cu.gbr, peautkb-B_Mask.gbr, peautkb-B_Paste.gbr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]
2021-04-28 debugging i2c issues
2021-05-05 adds rotary encoder and first attempt at media keys
2021-05-07 adds ctrl-tab on the left encoder layer 1, pushes events into rotary from main
2021-05-10 current layer
2021-05-10 working apart from intermitant stuck keys
    [display.rs, leds.rs, main.rs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]
2021-05-11 move encoders to interrupt driven, fix tick() being called appropriately
    [leds.rs, main.rs, rotary.rs]
2021-05-18 adds case stls
    [base.stl, plate.stl]
2021-05-18 cleans up pcb files
    [peautkb-B_Cu.gbr, peautkb-B_Mask.gbr, peautkb-B_Paste.gbr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]
2021-06-17 leds with menu for changing mode and colour
2021-06-25 dma spi working leds example
    [peautkb.kicad_pcb]
2021-06-25 leds working with dma spi
2021-06-28 fade led, keymap update and LED sleep
2021-11-14 adds right hand stls
    [base-left.stl, base-right.stl, plate-left.stl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]
2022-03-02 moves to git based deps for changes + fade led pattern
